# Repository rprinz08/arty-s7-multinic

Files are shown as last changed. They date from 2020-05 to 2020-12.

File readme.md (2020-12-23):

# Arty-S7-50, VexRiscV, Migen, LiteX, MulitNet

This project describes how to build a soft-core RiscV based system with multiple
Ethernet interfaces on a Digilent Arty-S7-50 with a Xilinx Spartan 7 FPGA using
Python based Migen HDL and LiteX SoC builder.

Prototype of the project
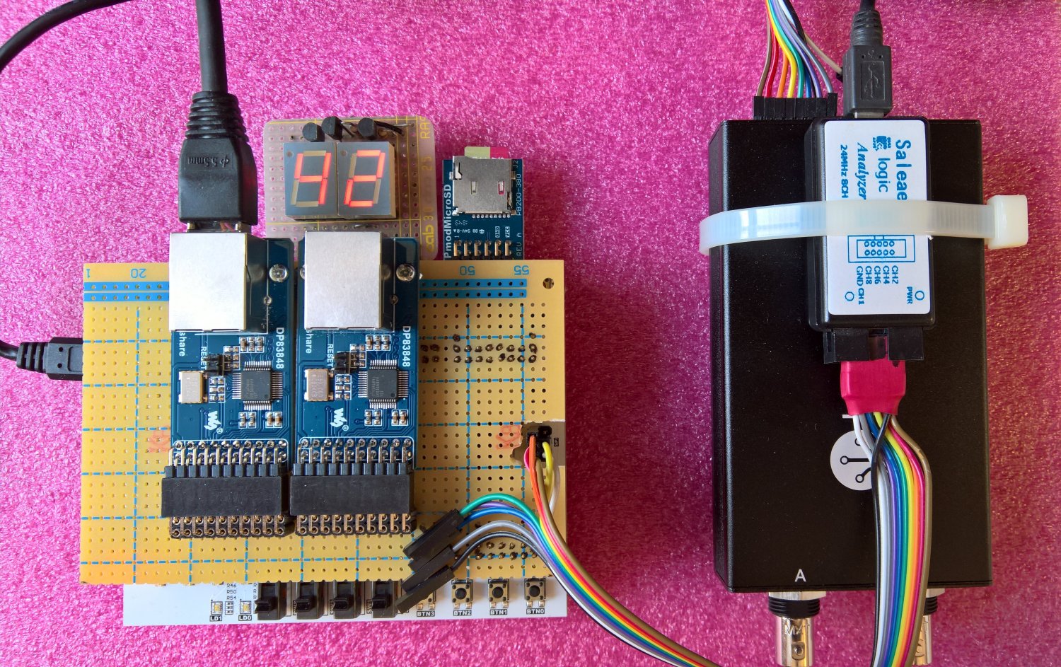
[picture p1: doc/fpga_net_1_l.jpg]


More evolved version with up to four Ethernet interfaces and a PCB. The [KiCad](https://kicad-pcb.org/) project files are included in this repository.
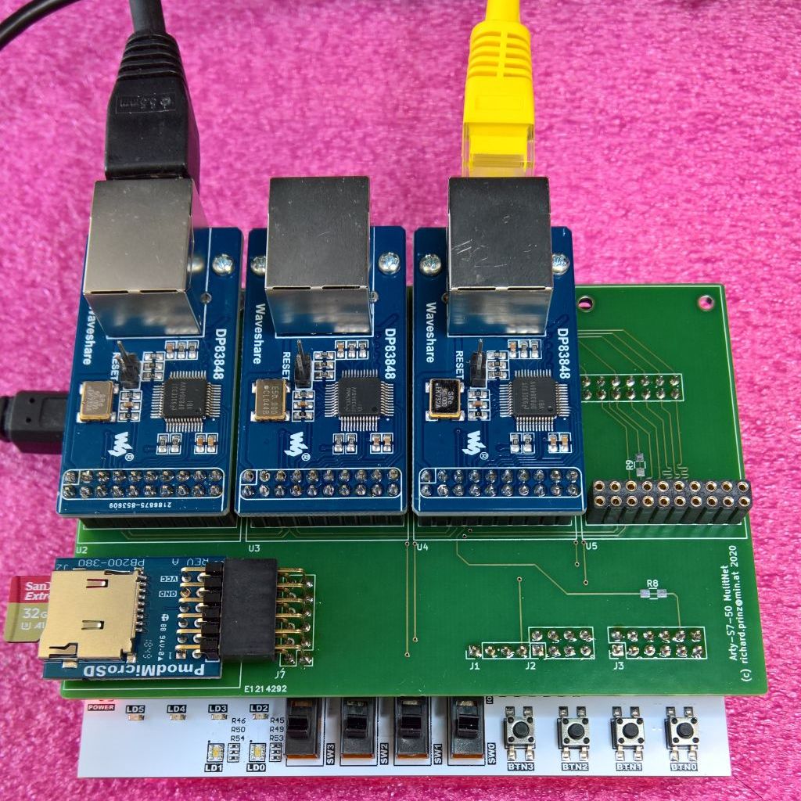
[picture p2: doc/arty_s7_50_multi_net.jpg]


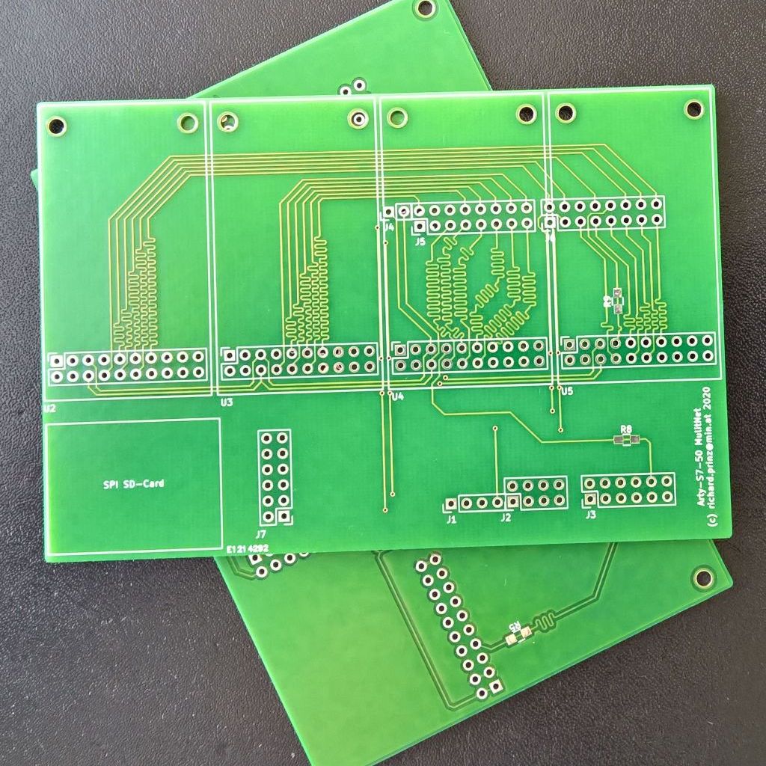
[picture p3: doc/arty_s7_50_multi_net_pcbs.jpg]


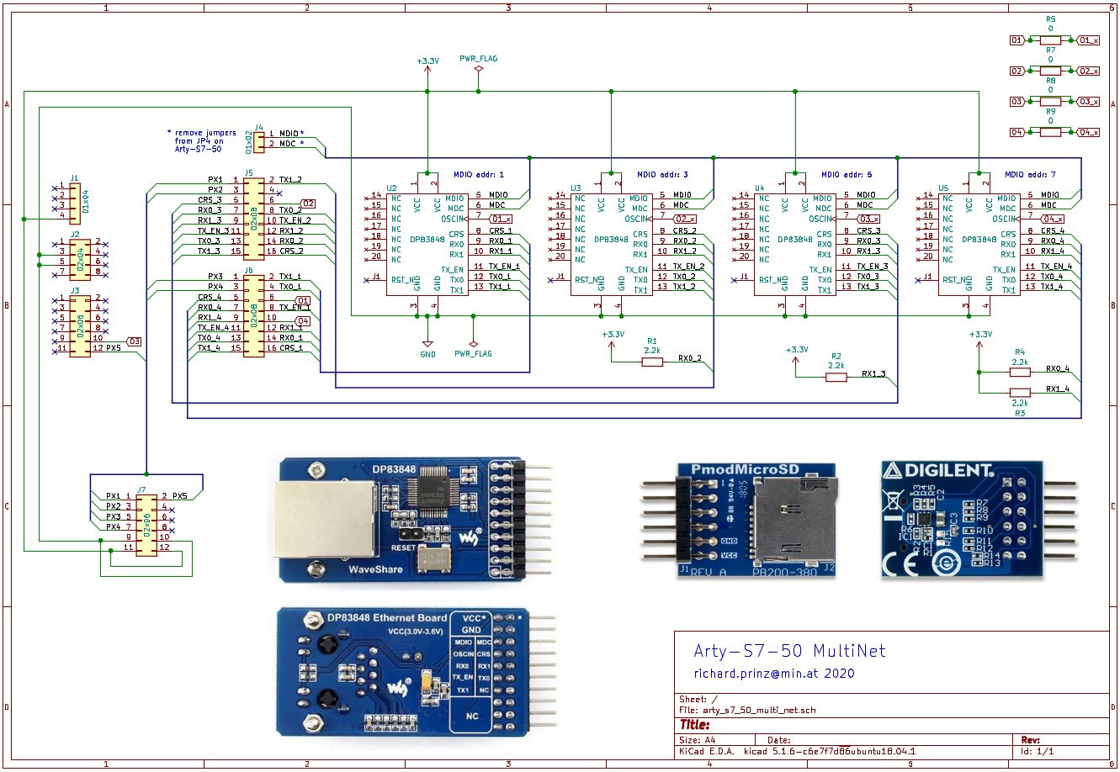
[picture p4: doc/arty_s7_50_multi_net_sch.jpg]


Download schematic as [PDF](doc/arty_s7_50_multi_net_sch.pdf).

It uses multiple [Texas Instruments DP83848](http://www.ti.com/product/DP83848-EP)
based RMII Ethernet PHYs from [Waveshare](https://www.waveshare.com/dp83848-ethernet-board.htm).
In addition a [SD-Card PMOD](https://store.digilentinc.com/pmod-microsd-microsd-card-slot/) completes the system.

Note: in the PCB version the Seven Segment Display was removed due to I/O limitations.

More infos about this project can be found in the accompanying blog posts
[here](https://www.min.at/prinz/?x=entry:entry200428-150015) and [here](https://www.min.at/prinz/?x=entry:entry200602-105212).

## Prerequisites

To build the FPGA bitstream, the SoC BIOS and the sample bare metal demo
application you need some prerequisites installed:

* [Xilinx Vivado](https://www.xilinx.com/products/design-tools/vivado.html)
* [Python >= 3.6](https://www.python.org/)
* [LiteX](https://github.com/enjoy-digital/litex)
  * Tested with git version (bddb170)
* [Liteeth](https://github.com/enjoy-digital/liteeth)
  * Tested with git version (dea3590)
* [RiscV compiler toolchain](https://static.dev.sifive.com/dev-tools/riscv64-unknown-elf-gcc-8.1.0-2019.01.0-x86_64-linux-ubuntu14.tar.gz)
* [OpenOCD](http://openocd.org/)
* [xc3sprog](https://sourceforge.net/projects/xc3sprog/) (optional)

*Note: As of LiteX version (bddb170) and Liteeth version (dea3590) no patches are needed for multiple ethernet support. If you use an older version you can find patches in the history.*

## Building

The included `make.py` script is responsible for building and loading/flashing.
In addition a `Makefile` is used to handle dependencies and file changes.
Assuming that all prerequisites are correctly installed using make:
```
make                Builds FPGA bitstream and BIOS software
make build-sw       Builds BIOS
make build-fpga     Builds FPGA bitstream
make conv           Convert Python FHDL to Verilog
make load           Loads bitstream into FPGA via serial port
make load-sw        Loads firmware binary using serial port
make reload         Same as "load" but does not rebuild in case of changes
make flash          Stores bitstream into FPGA boot flash
make flash-sw       Flash BIOS software
make reflash        Same as "flash" but does not rebuild in case of changes
make term           Opens LiteX serial lxterm console
make clean          Cleans/removes all build artefacts
```
The `make.py` script is called from make (Makefile) and provides the following:
```
make.py --help      shows basic help
make.py build       converts LiteX/Migen FHDL into verilog,
                    starts Xilinx Vivado and generates FPGA bitstream
make.py build-sw    same as 'build' but only builds BIOS
make.py build-fpga  same as 'build' but only builds FPGA bitstream
make.py load        loads the bitstream into FPGA
make.py flash       flashes the bitstream into config flash
make.py flash-sw    flashes the BIOS into config flash
make.py conv        creates all artefacts (verilog, c sources etc.)
                    but does not compile
```
In addition to the FPGA bitstream (which also includes the BIOS) a sample
application is included in the `firmware` directory. It can be compiled with
the included Makefile. The resulting `firmware.bin` can be loaded from SD-Card
or via TFTP from a server.

To load from SD-Card create a FAT16 partition on it and place `firmware.bin`
renamed to `boot.bin` in the root directory.

To load from TFTP server connect Ethernet interface 1 to a switch or directly
to a host via a cros-over network cable. Interface 1 is per default configured
with IP4 address **10.0.0.50** and tries to load from TFTP server with address
**10.0.0.100**. These addresses are static and can only be changed by modifying
`top.py` and re-building.
Place `firmware.bin` renamed to `BOOT.BIN` in the root directory of the TFTP
server.

To preserve the limited I/Os of the Arty the SD-Card can be removed and the
firmware booted from the SPI flash. The Arty has 16MB SPI flash normally used
to configure the FPGA with a bitstream at boot.
As lang as bitstream size + firmware size < 15MB they can reside together in
the flash. Current configuration halfs the flash. First half used for the
bitsream second half for the firmware. The `make flash-sw` writes the
`firmware.fbi` to flash adress 0x800000.

*Note: Due to BIOS ROM size limitations the option to boot from SPI flash has been disabled. Booting the system is possible via SPI SD-Card, TFTP and serial.*

## Running

Build and flash the FPGA bitstream:
```
make
make flash
```
To boot from SD-Card place `firmware.bin` renamed to `BOOT.BIN` on SD-Card and
reset the board. To boot from SPI flash, flash with `make flash-sw`.
On an attached serial terminal (open one with `make term`) you should see the
following output:
```
[LXTERM] Starting...
        __   _ __      _  __
       / /  (_) /____ | |/_/
      / /__/ / __/ -_)>  <
     /____/_/\__/\__/_/|_|
   Build your hardware, easily!

 (c) Copyright 2012-2020 Enjoy-Digital
 (c) Copyright 2007-2015 M-Labs

 BIOS built on May  1 2020 22:04:43
 BIOS CRC passed (f662f7bd)

 Migen git sha1: --------
 LiteX git sha1: 56aa7897

--=============== SoC ==================--
CPU:       VexRiscv @ 100MHz
ROM:       32KB
SRAM:      4KB
L2:        8KB
MAIN-RAM:  262144KB

--========== Initialization ============--
Ethernet init...
Initializing SDRAM...
SDRAM now under software control
Read leveling:
m0, b0: |00000000000000000000000000000000| delays: -
m0, b1: |00000000000000000000000000000000| delays: -
m0, b2: |00000000000000000000000000000000| delays: -
m0, b3: |00000000000000000000000000000000| delays: -
m0, b4: |00000000000000000000000000000000| delays: -
m0, b5: |00000000000000000000000000000000| delays: -
m0, b6: |00001111111111111000000000000000| delays: 10+-06
m0, b7: |00000000000000000000000000000000| delays: -
best: m0, b6 delays: 10+-06
m1, b0: |00000000000000000000000000000000| delays: -
m1, b1: |00000000000000000000000000000000| delays: -
m1, b2: |00000000000000000000000000000000| delays: -
m1, b3: |00000000000000000000000000000000| delays: -
m1, b4: |00000000000000000000000000000000| delays: -
m1, b5: |10000000000000000000000000000000| delays: 00+-00
m1, b6: |00001111111111111000000000000000| delays: 10+-06
m1, b7: |00000000000000000000000000000000| delays: -
best: m1, b6 delays: 10+-06
SDRAM now under hardware control
Memtest OK
Memspeed Writes: 262Mbps Reads: 327Mbps

--============== Boot ==================--
Booting from serial...
Press Q or ESC to abort boot completely.
sL5DdSMmkekro
Timeout
SD Card via SPI Initialising
Reading MBR
Partition 1 Information: Active=0x00, Type=0x06, LBAStart=0x00000800
Partition 1 is FAT16

Read FAT16 Boot Sector
  Jump Code:              0xeb 0x3c 0x90
  OEM Code:               [mkfs.fat]
  Sector Size:            512
  Sectors Per Cluster:    128
  Reserved Sectors:       128
  Number of Fats:         2
  Root Dir Entries:       2048
  Total Sectors Short:    0
  Media Descriptor:       0xf8
  Fat Size Sectors:       128
  Sectors Per Track:      32
  Number of Heads:        64
  Hidden Sectors:         2048
  Total Sectors Long:     4194304
  Drive Number:           0x80
  Current Head:           0x01
  Boot Signature:         0x29
  Volume ID:              0x3fab9b48
  Volume Label:           [LITEX      ]
  Volume Label:           [FAT16   ]
  Boot Sector Signature:  0xaa55

Reclocking from 400KHz to 14285KHz

sdCardFatTable = 0x4fff0000  Reading Fat16 Table (128 Sectors Long)

sdCardFat16RootDir = 0x4ffe0000  Reading Root Directory (128 Sectors Long)

Root Directory
  File 1 [BOOT    .BIN] @ Cluster 3 for 9532 bytes

Reading File [BOOT.BIN] into 0x40000000 : File starts at Cluster 3 length 9532
Clusters: 3

Executing booted program at 0x40000000

--============= Liftoff! ===============--
Hello firmware booting...

HELLO>
```

## Debugging

A [Litescope](https://github.com/enjoy-digital/litescope) debugger is available via eth2 with configured IP address of **10.0.0.42**. The `debug` directory contains some scripts and samples on how to use it.

## Firmware

After board reset the embedded BIOS is started which performs some basic
initalization and then tries to load the firmware via available peripherals.
In this case first via serial port, then via SD-Card and last via Ethernet.
It found the BOOT.BIN `hello` firmware on the SD-Card and loads it.

```
HELLO >help

Available commands:
hello value      - Returns value xor'ed with 0xff in FPGA
time             - show current clock ticks
uptime           - show system uptime in seconds
random [runs]    - show random number generator values, default [500] runs
malloc [runs]    - test UMM malloc, default [500] runs
ping             - ping host (10.0.0.100) via network interface (eth0)
reboot           - reboot CPU
help             - this command
```

The `hello` firmware just shows how to develop bare metal applications using
console in- and output and accessing FPGA logic blocks. Details about the firmware can be found [here](doc/firmware.md).

## RMII notes

Although there exists a OSCIN pin on the DP83848 PHY module which
suggests a clock input, it is the output of the 50MHz oscillator
available on the module. This oscillator directly clocks the DP83848
PHY and is available on the module connector as reference clock
output.

The default LiteX Liteeth RMII MAC operates with the clock of a 50MHz
PLL it instantiates assuming that it must provide the clock to the
PHY. As the PHY modules use their own oscillator the corresponding clock pads are set to Null in the code so that the external clock will be used.

To synchronize the MAC with the PHY the PHYs clock can be
used as input to the MAC instead of the default 50MHz PLL clock
output. 

On Xilinx Spartan7 FPGAs only the positive (P) version of clock
capable (CC) pins can be used as they are internally special wired
and there is only a limited number per I/O bank available.
As each module has its own oscillator they should be synced to its
corresponding MAC. This is somehow inefficient as normally multiple PHYs and
MACs share a common clock. But to prevent modifying each module, each modules
OSCIN is connected to one of four CC-P pin on
the FPGA syncing its corresponding MAC.

Although a simple modification on the module makes it possible to
share clocks. Removing the 0 Ohm resistor R1 makes it possible to clock the
modules from outside via the OSCIN pin.

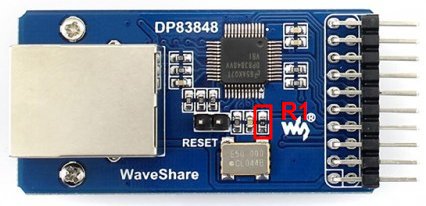
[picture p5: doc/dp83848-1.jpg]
x


More infos about this project can be found in the accompanying blog posts
[here](https://www.min.at/prinz/?x=entry:entry200428-150015) and [here](https://www.min.at/prinz/?x=entry:entry200602-105212).

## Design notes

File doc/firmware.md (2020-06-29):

# Demo Firmware

The included demo firmware is used to try out concepts and to
show sample code.

* Included is a sample on how to use [Configuration Status Registers (CSR)](https://github.com/enjoy-digital/litex/wiki/CSR-Bus) to talk to the FPGA from firmware. The `echo` sample sends a byte to the FPGA gateware where it is XOR'ed with 0xff and the result returned to the firmware which is then displayed on the serial console.

* The `time` sample shows the free running CPU clock cycle ticker and
derived millisecond subticker in FPGA. The later is used by the 
network stack described below.

* `uptime` shows the time elapsed since boot

* A simple [Pseudo Random Number Generator PRNG](https://en.wikipedia.org/wiki/Pseudorandom_number_generator) is included in the gateware. 
It is based on a [Linear Feedback Shift Register (LFSR)](https://en.wikipedia.org/wiki/Linear-feedback_shift_register) configured as [Pseudo Random Binary Sequence (PRBS31)](https://en.wikipedia.org/wiki/Pseudorandom_binary_sequence). Its output can be shown with `random [runs]` and an optional value how many numbers to display (default 500).

* The firmware includes the [umm_malloc Memory Manager](https://github.com/rhempel/umm_malloc) which enables dynamic memory allocations ([malloc, free](https://man7.org/linux/man-pages/man3/malloc.3.html)). The `malloc [runs]` command performs a simple test allocating an amount of memory, fill it with data, read it back, and compare the results. An optional value specifies how often this test should be performed (default 500).

* [PicoTCP](https://github.com/tass-belgium/picotcp) is a very lightwight network stack which is included in the firmware. The demo `ping` command pings (IP4, ICMP) a target host. It uses the first network interface. Configuration (Ethernet MAC address, IP4 address, netmask, ping target IP4 address and number of pings) can be found in `config.h`. The files `network.c` and `network_if.c` show how to initialize and use PicoTCP and how a device driver for LiteX Liteeth looks.

The following log shows a sample run of the firmware:
```
VEXRISCV
[LXTERM] Starting....

        __   _ __      _  __
       / /  (_) /____ | |/_/
      / /__/ / __/ -_)>  <
     /____/_/\__/\__/_/|_|
   Build your hardware, easily!

 (c) Copyright 2012-2020 Enjoy-Digital
 (c) Copyright 2007-2015 M-Labs

 BIOS built on Jun 17 2020 17:05:47
 BIOS CRC passed (707679a9)

 Migen git sha1: b1b2b29
 LiteX git sha1: efbe1690

--=============== SoC ==================--
CPU:       VexRiscv @ 100MHz
BUS:       WISHBONE 32-bit - 4GiB
CSR:       8-bit data
ROM:       32KiB
SRAM:      4KiB
L2:        8KiB
MAIN-RAM:  262144KiB

--========== Initialization ============--
Ethernet init...
Initializing SDRAM...
SDRAM now under software control
SDRAM now under software control
Read leveling:
m0, b00: |00000000000000000000000000000000| delays: -
m0, b01: |00000000000000000000000000000000| delays: -
m0, b02: |00000000000000000000000000000000| delays: -
m0, b03: |00000000000000000000000000000000| delays: -
m0, b04: |00000000000000000000000000000000| delays: -
m0, b05: |00000000000000000000000000000000| delays: -
m0, b06: |00000000000000000000000000000000| delays: -
m0, b07: |00000000000000000000000000000000| delays: -
m0, b08: |00000000000000000000000000000000| delays: -
m0, b09: |00000000000000000000000000000000| delays: -
m0, b10: |00000000000000000000000000000000| delays: - 
m0, b11: |00000000000000000000000000000000| delays: -
m0, b12: |00000000000000000000000000000000| delays: -
m0, b13: |11000000000000000000000000000000| delays: 00+-00
m0, b14: |00001111111111111100000000000000| delays: 11+-07
m0, b15: |00000000000000000000111111111111| delays: 26+-06
best: m0, b14 delays: 11+-07
m1, b00: |00000000000000000000000000000000| delays: -
m1, b01: |00000000000000000000000000000000| delays: -
m1, b02: |00000000000000000000000000000000| delays: -
m1, b03: |00000000000000000000000000000000| delays: -
m1, b04: |00000000000000000000000000000000| delays: -
m1, b05: |00000000000000000000000000000000| delays: -
m1, b06: |00000000000000000000000000000000| delays: -
m1, b07: |00000000000000000000000000000000| delays: -
m1, b08: |00000000000000000000000000000000| delays: -
m1, b09: |00000000000000000000000000000000| delays: -
m1, b10: |00000000000000000000000000000000| delays: -
m1, b11: |00000000000000000000000000000000| delays: -
m1, b12: |00000000000000000000000000000000| delays: -
m1, b13: |00000000000000000000000000000000| delays: 00+-00
m1, b14: |00000111111111111100000000000000| delays: 11+-06
m1, b15: |00000000000000000000111111111111| delays: 26+-06
best: m1, b14 delays: 11+-06
SDRAM now under hardware control
Memtest OK
Memspeed Writes: 229Mbps Reads: 327Mbps

--============== Boot ==================--
Booting from serial...
Press Q or ESC to abort boot completely.
sL5DdSMmkekro
[LXTERM] Received firmware download request from the device.
[LXTERM] Uploading ./firmware.bin to 0x40000000 (288804 bytes)...
[LXTERM] Upload complete (3.7KB/s).
[LXTERM] Booting the device.
[LXTERM] Done.
Executing booted program at 0x40000000

--============= Liftoff! ===============--
net_init: Start ...
eth_init: ...
Network interfaces: (3)
eth_init: Done
pTCP: Init
Protocol ethernet registered (layer: 2).
Protocol ipv4 registered (layer: 3).
Protocol ipv6 registered (layer: 3).
Protocol icmp4 registered (layer: 4).
Protocol icmp6 registered (layer: 4).
Protocol igmp registered (layer: 4).
Protocol udp registered (layer: 4).
Protocol tcp registered (layer: 4).
pTCP: Create device (eth0)
pTCP: MAC address (00:01:bb:08:15:00)
pTCP: Set device (eth0) IP4 address to (10.0.0.50)
pTCP: Set device (eth0) IP4 netmask to (255.255.255.0)
pTCP: Add device (eth0) to stack
Assigned ipv4 10.0.0.50 to device eth0
net_init: Done
Hello firmware booting...

HELLO >
IPv6: DAD verified valid address.

HELLO >help

Available commands:
hello value      - Returns value xor'ed with 0xff in FPGA
time             - show current clock ticks
uptime           - show system uptime in seconds
random [runs]    - show random number generator values, default [500] runs
malloc [runs]    - test UMM malloc, default [500] runs
ping             - ping host (10.0.0.100) via network interface (eth0)
reboot           - reboot CPU
help             - this command

HELLO >ping

Ping: Start ...
pTCP: Ping (10.0.0.100) for (10) times
64 bytes from 10.0.0.100: icmp_req=1 ttl=64 time=4 ms
64 bytes from 10.0.0.100: icmp_req=2 ttl=64 time=2 ms
64 bytes from 10.0.0.100: icmp_req=3 ttl=64 time=2 ms
64 bytes from 10.0.0.100: icmp_req=4 ttl=64 time=2 ms
64 bytes from 10.0.0.100: icmp_req=5 ttl=64 time=2 ms
64 bytes from 10.0.0.100: icmp_req=6 ttl=64 time=2 ms
64 bytes from 10.0.0.100: icmp_req=7 ttl=64 time=2 ms
64 bytes from 10.0.0.100: icmp_req=8 ttl=64 time=2 ms
64 bytes from 10.0.0.100: icmp_req=9 ttl=64 time=2 ms
64 bytes from 10.0.0.100: icmp_req=10 ttl=64 time=2 ms

Ping: Done

HELLO >

```

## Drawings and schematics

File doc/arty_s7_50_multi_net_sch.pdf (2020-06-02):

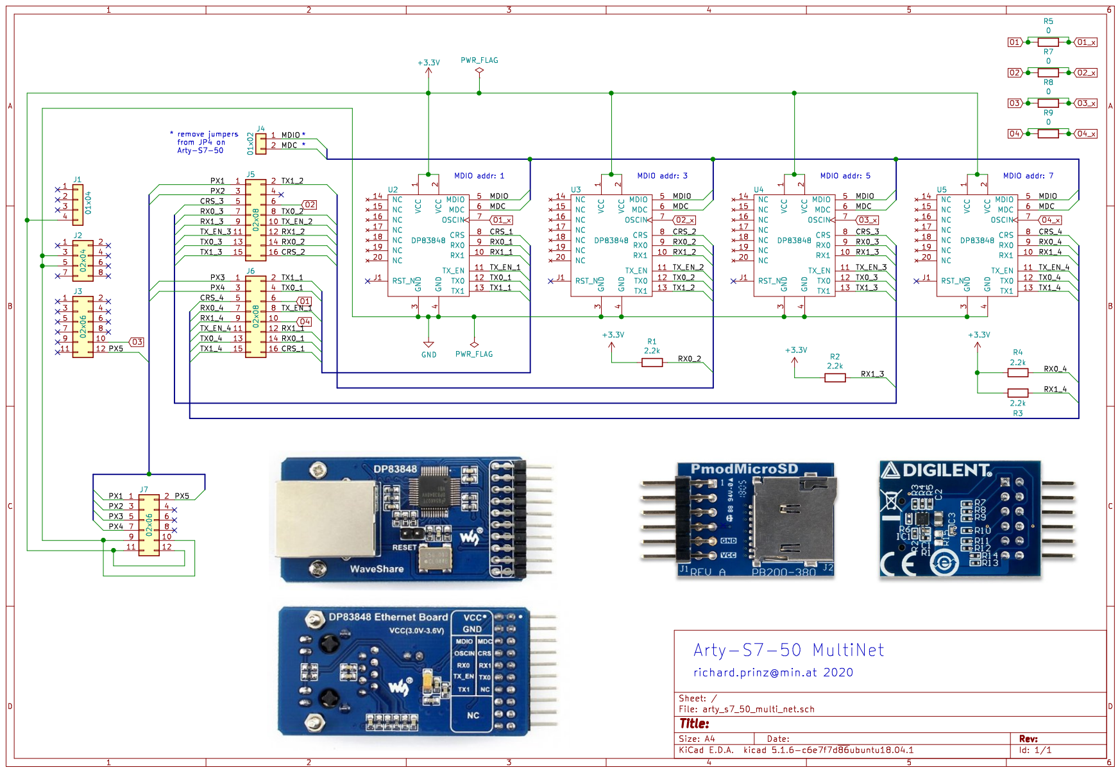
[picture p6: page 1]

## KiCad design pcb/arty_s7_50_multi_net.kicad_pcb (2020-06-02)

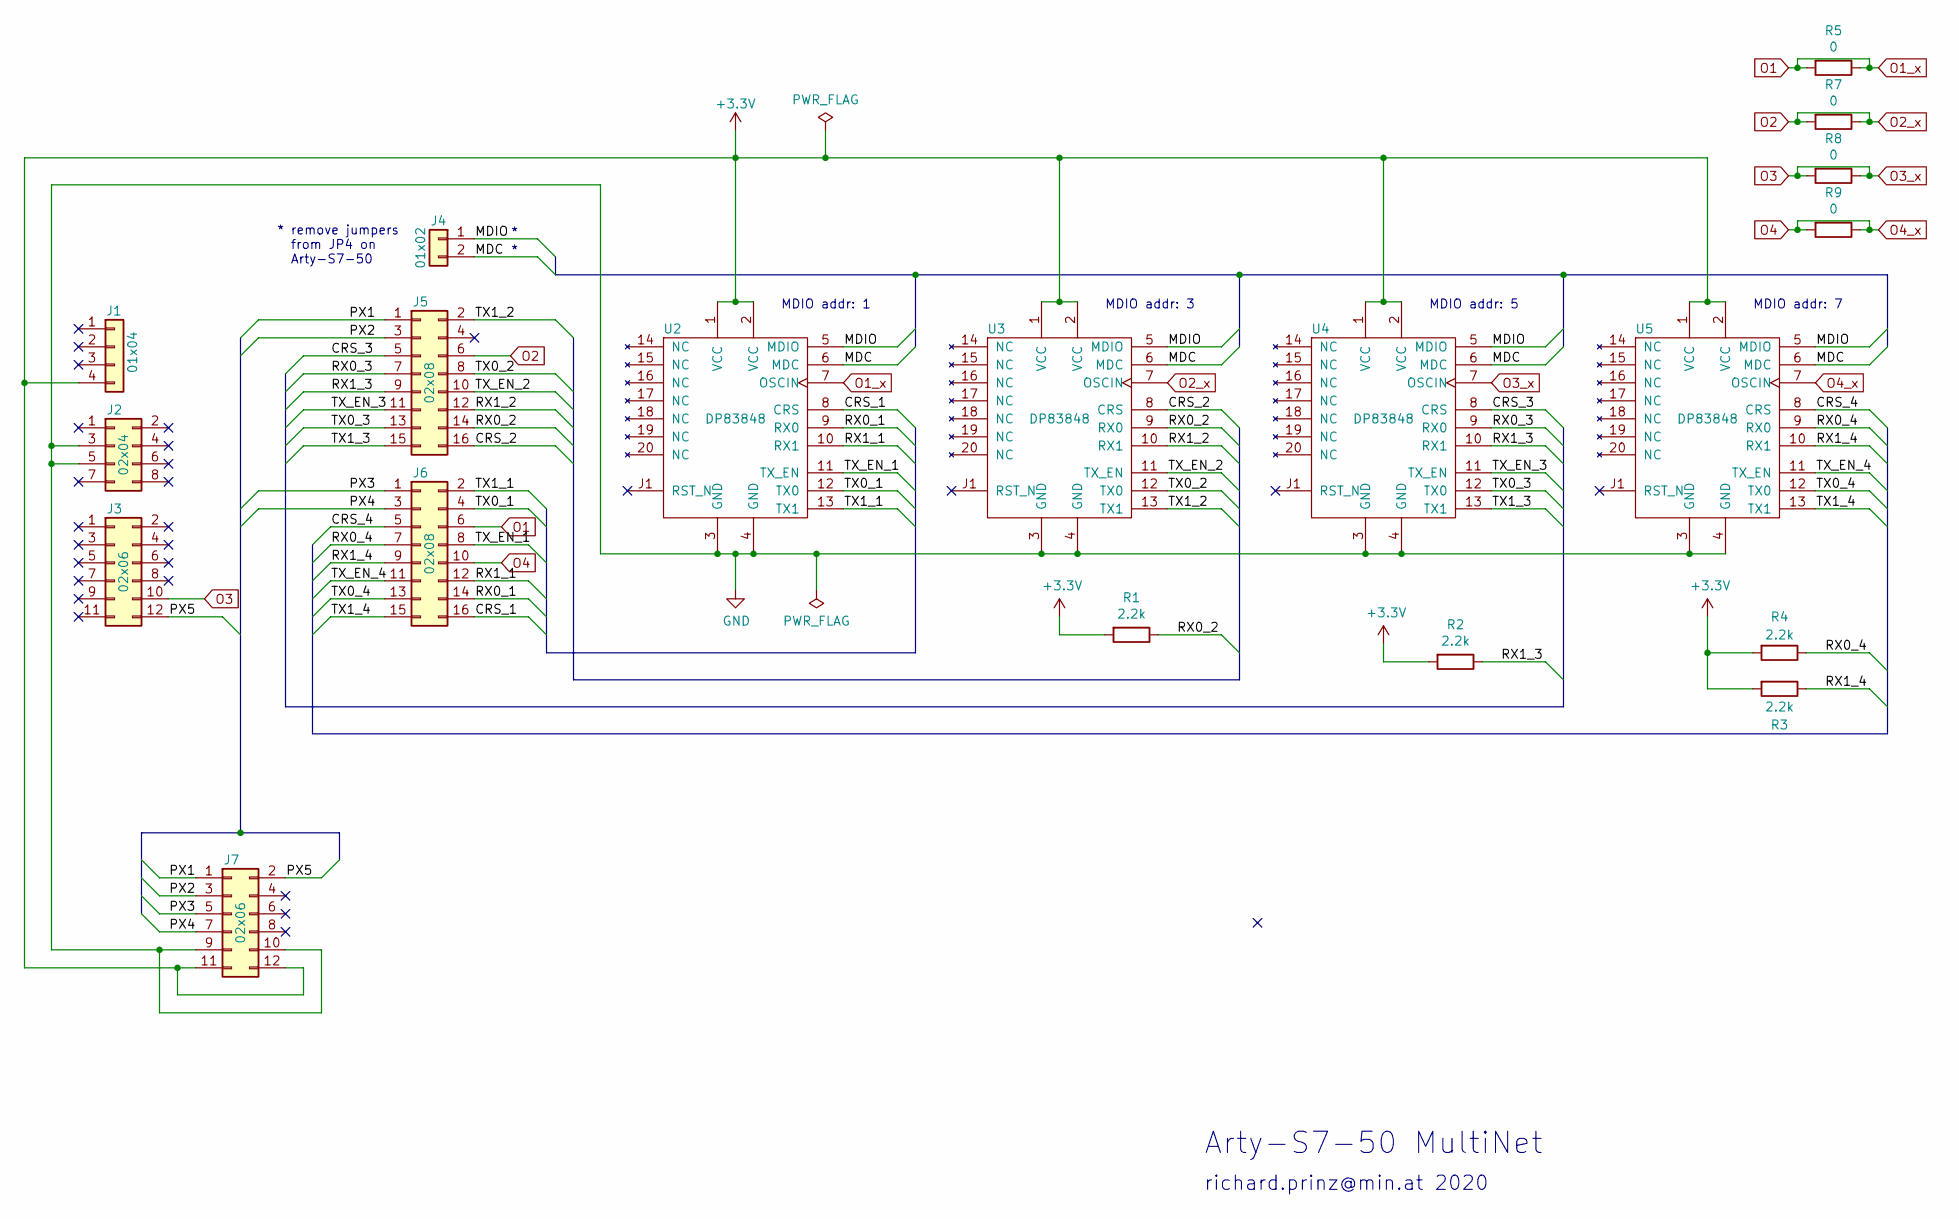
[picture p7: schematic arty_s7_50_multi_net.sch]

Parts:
J1: 01x04; Pin_Header_Straight_1x04_Pitch2.54mm
J2: 02x04; Pin_Header_Straight_2x04_Pitch2.54mm
J3, J7: 02x06; Pin_Header_Straight_2x06_Pitch2.54mm
J4: 01x02; Pin_Header_Straight_1x02_Pitch2.54mm
J5, J6: 02x08; Pin_Header_Straight_2x08_Pitch2.54mm
R1, R2, R3, R4: 2.2k; R_0805_HandSoldering
R5, R7, R8, R9: 0; R_0805_HandSoldering
U2, U3, U4, U5: DP83848; Socket_Strip_Straight_2x10_Pitch2.54mm

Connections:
+3V3: J1.4, J7.11, J7.12, R1.2, R2.2, R3.2, R4.2, U2.1 (VCC), U2.2 (VCC), U3.1 (VCC), U3.2 (VCC), U4.1 (VCC), U4.2 (VCC), U5.1 (VCC), U5.2 (VCC)
/CRS_1: J6.16, U2.8 (CRS)
/CRS_2: J5.16, U3.8 (CRS)
/CRS_3: J5.5, U4.8 (CRS)
/CRS_4: J6.5, U5.8 (CRS)
/MDC: J4.2, U2.6 (MDC), U3.6 (MDC), U4.6 (MDC), U5.6 (MDC)
/MDIO: J4.1, U2.5 (MDIO), U3.5 (MDIO), U4.5 (MDIO), U5.5 (MDIO)
/PX1: J5.1, J7.1
/PX2: J5.3, J7.3
/PX3: J6.1, J7.5
/PX4: J6.3, J7.7
/PX5: J3.12, J7.2
/RX0_1: J6.14, U2.9 (RX0)
/RX0_2: J5.14, R1.1, U3.9 (RX0)
/RX0_3: J5.7, U4.9 (RX0)
/RX0_4: J6.7, R4.1, U5.9 (RX0)
/RX1_1: J6.12, U2.10 (RX1)
/RX1_2: J5.12, U3.10 (RX1)
/RX1_3: J5.9, R2.1, U4.10 (RX1)
/RX1_4: J6.9, R3.1, U5.10 (RX1)
/TX0_1: J6.4, U2.12 (TX0)
/TX0_2: J5.8, U3.12 (TX0)
/TX0_3: J5.13, U4.12 (TX0)
/TX0_4: J6.13, U5.12 (TX0)
/TX1_1: J6.2, U2.13 (TX1)
/TX1_2: J5.2, U3.13 (TX1)
/TX1_3: J5.15, U4.13 (TX1)
/TX1_4: J6.15, U5.13 (TX1)
/TX_EN_1: J6.8, U2.11 (TX_EN)
/TX_EN_2: J5.10, U3.11 (TX_EN)
/TX_EN_3: J5.11, U4.11 (TX_EN)
/TX_EN_4: J6.11, U5.11 (TX_EN)
GND: J2.3, J2.5, J7.9, J7.10, U2.3 (GND), U2.4 (GND), U2.19 (NC), U2.20 (NC), U3.3 (GND), U3.4 (GND), U3.19 (NC), U3.20 (NC), U4.3 (GND), U4.4 (GND), U4.19 (NC), U4.20 (NC), U5.3 (GND), U5.4 (GND), U5.19 (NC), U5.20 (NC)
O1: J6.6, R5.1, R5.2, U2.7 (OSCIN)
O2: J5.6, R7.1, R7.2, U3.7 (OSCIN)
O3: J3.10, R8.1, R8.2, U4.7 (OSCIN)
O4: J6.10, R9.1, R9.2, U5.7 (OSCIN)

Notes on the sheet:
* remove jumpers from JP4 on Arty-S7-50
Arty-S7-50 MultiNet
richard.prinz@min.at 2020
MDIO addr: 1
MDIO addr: 3
MDIO addr: 5
MDIO addr: 7

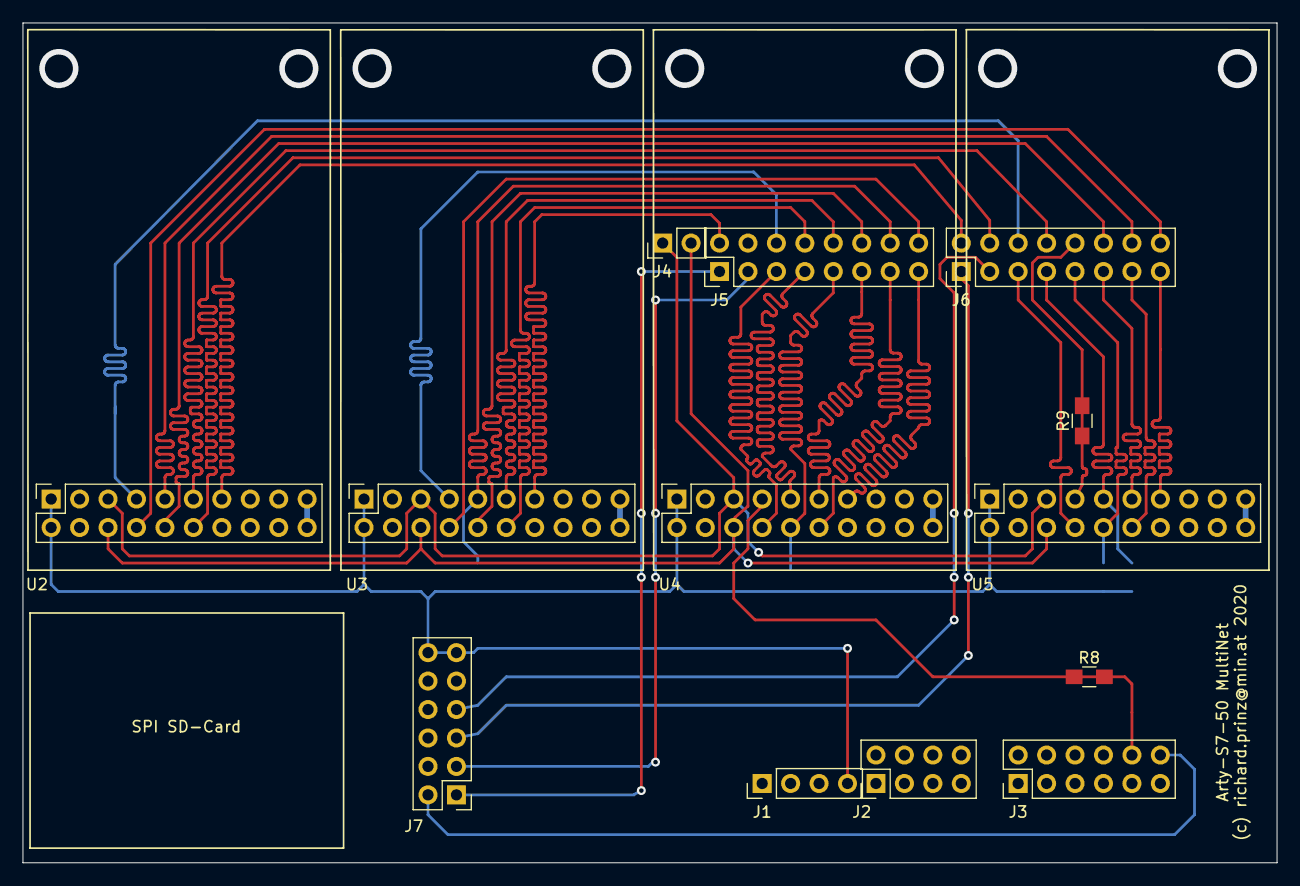
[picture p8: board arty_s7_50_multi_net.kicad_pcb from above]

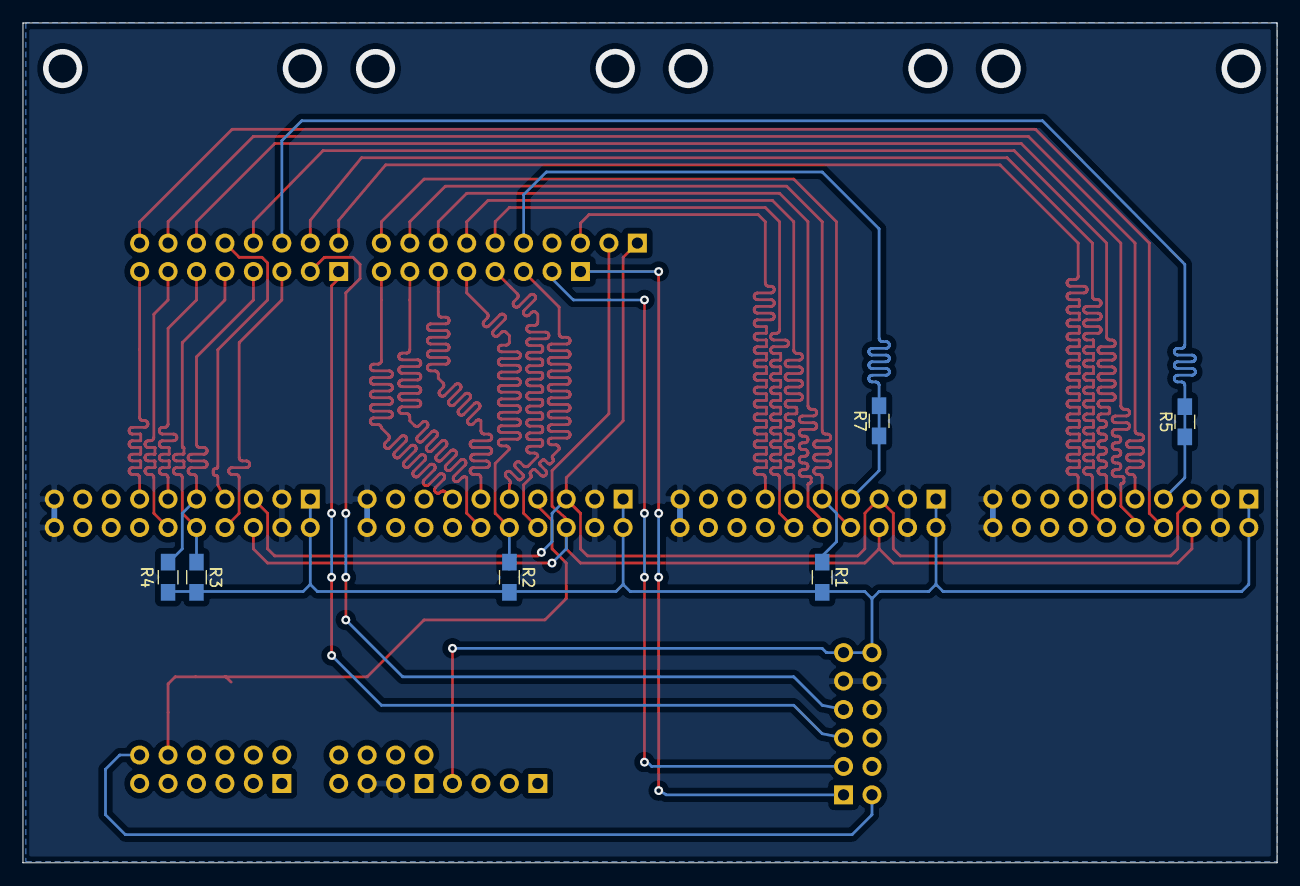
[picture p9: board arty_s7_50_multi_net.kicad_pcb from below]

Board: 2 copper layers, 112.0 x 75.0 mm, 19 parts (6 on the bottom side), 37 nets.

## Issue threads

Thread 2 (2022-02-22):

Using this project for Ethernet Tap monitoring

hotteshen, 2022-02-22:
Thank you for the great work.
I made the PCB and configured exactly the same modules and boards.

I want to set up this as an Ethernet pass-through to get packet data in the middle.
Is it possible to do it with LiteEth?

rprinz08, 2022-02-23:
Thx. This should be possible with two LiteEthMACCore's back-to-back and whatever you want to do in between. An example can be found [here](https://github.com/rprinz08/hBPF/tree/main/source/fpga/hw/arty-s7-50-nic) ...

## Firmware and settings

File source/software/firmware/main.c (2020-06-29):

#include <stdio.h>
#include <stdlib.h>
#include <stdbool.h>
#include <stdint.h>
#include <string.h>

#include <irq.h>
#include <uart.h>
#include <time.h>
#include <console.h>
#include <generated/csr.h>
#include <generated/mem.h>

#include "stdio_wrap.h"
#include "system.h"
#include "network.h"
#include "ci.h"

int main(void)
{
    irq_setmask(0);
    irq_setie(1);
    uart_init();
    time_init();
    umm_init();
#ifdef CSR_ETHMAC_BASE
    net_init();
#endif

    wputs("Hello firmware booting...\n");

    ci_prompt();
    while(1) {
        ci_service();
        net_service();
    }

    return 0;
}

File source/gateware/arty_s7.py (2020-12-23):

# This file is Copyright (c) 2020 Richard Prinz <richard.prinz@min.at>
# License: BSD

from litex.build.generic_platform import *
from litex.build.xilinx import XilinxPlatform, XC3SProg, VivadoProgrammer
from litex.build.openocd import OpenOCD

# IOs ----------------------------------------------------------------------------------------------

_io = [
    ("user_led", 0, Pins("E18"), IOStandard("LVCMOS33")),
    ("user_led", 1, Pins("F13"), IOStandard("LVCMOS33")),
    ("user_led", 2, Pins("E13"), IOStandard("LVCMOS33")),
    ("user_led", 3, Pins("H15"), IOStandard("LVCMOS33")),

    ("leds", 0, Pins("E18 F13 E13 H15"),
        IOStandard("LVCMOS33")),

    ("rgb_led", 0,
        Subsignal("r", Pins("J15")),
        Subsignal("g", Pins("G17")),
        Subsignal("b", Pins("F15")),
        IOStandard("LVCMOS33")
    ),

    ("rgb_led", 1,
        Subsignal("r", Pins("E15")),
        Subsignal("g", Pins("F18")),
        Subsignal("b", Pins("E14")),
        IOStandard("LVCMOS33")
    ),

    ("user_sw", 0, Pins("H14"), IOStandard("LVCMOS33")),
    ("user_sw", 1, Pins("H18"), IOStandard("LVCMOS33")),
    ("user_sw", 2, Pins("G18"), IOStandard("LVCMOS33")),
    ("user_sw", 3, Pins("M5"), IOStandard("SSTL135")),

    ("user_btn", 0, Pins("G15"), IOStandard("LVCMOS33")),
    ("user_btn", 1, Pins("K16"), IOStandard("LVCMOS33")),
    ("user_btn", 2, Pins("J16"), IOStandard("LVCMOS33")),
    ("user_btn", 3, Pins("H13"), IOStandard("LVCMOS33")),

    ("clk100", 0, Pins("R2"), IOStandard("SSTL135")),

    ("cpu_reset", 0, Pins("C18"), IOStandard("LVCMOS33")),

    ("serial", 0,
        Subsignal("tx", Pins("R12")),
        Subsignal("rx", Pins("V12")),
        IOStandard("LVCMOS33")),

    # Unavailable; used for Ethernet
    #("spi", 0,
    #    Subsignal("clk", Pins("G16")),
    #    Subsignal("cs_n", Pins("H16")), # SS
    #    Subsignal("mosi", Pins("H17")),
    #    Subsignal("miso", Pins("K14")),
    #    IOStandard("LVCMOS33")
    #),

    # When using an Arduino Wireless SD shield
    # https://store.arduino.cc/arduino-wireless-sd-shield
    #("spisdcard", 0,
    #    Subsignal("clk", Pins("G16")),
    #    Subsignal("cs_n", Pins("T14")), # CK_IO4
    #    Subsignal("mosi", Pins("H17")),
    #    Subsignal("miso", Pins("K14")),
    #    IOStandard("LVCMOS33")
    #),

    # For digilent PMOD SD-Card on PMOD-D
    # https://store.digilentinc.com/pmod-microsd-microsd-card-slot/
    #("spisdcard", 0,
    #    Subsignal("clk", Pins("T12")),
    #    Subsignal("cs_n", Pins("V15")),
    #    Subsignal("mosi", Pins("U12")),
    #    Subsignal("miso", Pins("V13")),
    #    IOStandard("LVCMOS33")
    #),

    # For digilent PMOD SD-Card on Arty-S7-50-MultiNet shield
    # https://store.digilentinc.com/pmod-microsd-microsd-card-slot/
    ("spisdcard", 0,
        Subsignal("clk", Pins("U12")),
        Subsignal("cs_n", Pins("U15")),
        Subsignal("mosi", Pins("V16")),
        Subsignal("miso", Pins("V15")),
        IOStandard("LVCMOS33")
    ),

    ("spiflash4x", 0,  # clock needs to be accessed through STARTUPE2
        Subsignal("cs_n", Pins("M13")),
        Subsignal("dq", Pins("K17", "K18", "L14", "M15")),
        IOStandard("LVCMOS33")
    ),

    ("spiflash", 0,  # clock needs to be accessed through STARTUPE2
        Subsignal("cs_n", Pins("M13")),
        Subsignal("mosi", Pins("K17")),
        Subsignal("miso", Pins("K18")),
        Subsignal("wp", Pins("L14")),
        Subsignal("hold", Pins("M15")),
        IOStandard("LVCMOS33")
    ),

    ("ddram", 0,
        Subsignal("a", Pins(
            "U2 R4 V2 V4 T3 R7 V6 T6",
            "U7 V7 P6 T5 R6 U6"),
            IOStandard("SSTL135")),
        Subsignal("ba", Pins("V5 T1 U3"), IOStandard("SSTL135")),
        Subsignal("ras_n", Pins("U1"), IOStandard("SSTL135")),
        Subsignal("cas_n", Pins("V3"), IOStandard("SSTL135")),
        Subsignal("we_n", Pins("P7"), IOStandard("SSTL135")),
        Subsignal("cs_n", Pins("R3"), IOStandard("SSTL135")),
        Subsignal("dm", Pins("K4 M3"), IOStandard("SSTL135")),
        Subsignal("dq", Pins(
            "K2 K3 L4 M6 K6 M4 L5 L6",
            "N4 R1 N1 N5 M2 P1 M1 P2"),
            IOStandard("SSTL135"),
            Misc("IN_TERM=UNTUNED_SPLIT_40")),
        Subsignal("dqs_p", Pins("K1 N3"), IOStandard("DIFF_SSTL135")),
        Subsignal("dqs_n", Pins("L1 N2"), IOStandard("DIFF_SSTL135")),
        Subsignal("clk_p", Pins("R5"), IOStandard("DIFF_SSTL135")),
        Subsignal("clk_n", Pins("T4"), IOStandard("DIFF_SSTL135")),
        Subsignal("cke", Pins("T2"), IOStandard("SSTL135")),
        Subsignal("odt", Pins("P5"), IOStandard("SSTL135")),
        Subsignal("reset_n", Pins("J6"), IOStandard("SSTL135")),
        Misc("SLEW=FAST"),
    ),

    # PMOD A
    ("pmoda", 0, Pins("L17 L18 M14 N14 M16 M17 M18 N18"),
        IOStandard("LVCMOS33")),

    # PMOD B
    ("pmodb", 0, Pins("P17 P18 R18 T18 P14 P15 N15 P16"),
        IOStandard("LVCMOS33")),

    # PMOD C
    ("pmodc", 0, Pins("U15 V16 U17 U18 U16 P13 R13 V14"),
        IOStandard("LVCMOS33")),

    # PMOD D
    ("pmodd", 0, Pins("V15 U12 V13 T12 T13 R11 T11 U11"),
        IOStandard("LVCMOS33")),

	# Ethernet 0
	("eth_clocks_ext", 0,
		Subsignal("ref_clk", Pins("R16")),
		IOStandard("LVCMOS33"),
	),
	("eth", 0,
		Subsignal("mdio", Pins("J14")),
		Subsignal("mdc", Pins("J13")),

		Subsignal("crs_dv", Pins("L13")),
		Subsignal("rx_data", Pins("N13 L16")),
		Subsignal("tx_data", Pins("R17 V17")),
		Subsignal("tx_en", Pins("T14")),
		IOStandard("LVCMOS33"),
	),

	# Ethernet 1
	("eth_clocks_ext", 1,
		Subsignal("ref_clk", Pins("G16")),
		IOStandard("LVCMOS33"),
	),
	("eth", 1,
        # connected to MDIO bus of eth0
		Subsignal("crs_dv", Pins("R15")),
		Subsignal("rx_data", Pins("T15 H16")),
		Subsignal("tx_data", Pins("K14 K13")),
		Subsignal("tx_en", Pins("H17")),
		IOStandard("LVCMOS33"),
	),

	# Ethernet 2
	("eth_clocks_ext", 2,
		Subsignal("ref_clk", Pins("D14")),
		IOStandard("LVCMOS33")
	),
	("eth", 2,
        # connected to MDIO bus of eth0
		Subsignal("crs_dv", Pins("U17")),
		Subsignal("rx_data", Pins("U18 U16")),
		Subsignal("tx_data", Pins("R13 V14")),
		Subsignal("tx_en", Pins("P13")),
		IOStandard("LVCMOS33")
	),

	# Ethernet 3
	("eth_clocks_ext", 3,
		Subsignal("ref_clk", Pins("R14")),
		IOStandard("LVCMOS33")
	),
	("eth", 3,
		# connected to MDIO bus of eth0
		Subsignal("crs_dv", Pins("V13")),
		Subsignal("rx_data", Pins("T12 T13")),
		Subsignal("tx_data", Pins("T11 U11")),
		Subsignal("tx_en", Pins("R11")),
		IOStandard("LVCMOS33")
	)
]

# Connectors ---------------------------------------------------------------------------------------
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

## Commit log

2020-05-09 Added OpenOCD and booting firmware from SPI flash
    [digilent-hs1.cfg, jtagspi.cfg, xilinx-xc7.cfg]
2020-05-12 Fixed boot from SPI flash
    [top.py]
2020-06-02 added KiCad PCB files
    [arty_s7_50_multi_net.kicad_pcb, arty_s7_50_multi_net.sch]
2020-06-29 fix for latest LiteX and SD-Card
    [arty_s7_50_multi_net.sch]
2020-11-01 Fixes to support latest LiteX
    [arty_s7.py, top.py]
2020-12-23 Latest LiteX and Liteeth no longer require patches - removed them
    [arty_s7.py, top.py]
